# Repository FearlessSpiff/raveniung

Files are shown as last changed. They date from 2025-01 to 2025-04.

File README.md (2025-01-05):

# raveniung

Keyboard designed with ergogen, heavenly inspired by the reviung34

## Setup

* Install ergogen: `npm install -g ergogen`
* Get footprints from ceoloide: `git clone https://github.com/ceoloide/ergogen-footprints ergogen/footprints/ceoloide`

## Build

```bash
cd ergogen
ergogen .
```

## Notes

### Laser cutting (CR-Falcon Laser 10W)

#### Flux Oak Wood 3mm

* Outline and switch holes: Cut 2 times with 5mm/s 90% power
* M2 holes: Cut 2 times with 5mm/s 100% power

### Measurements

#### With PCB as top-plate and 3mm acryl top middle plate

* Standoffs must be 6mm high, 3mm diameter
* Screw from bottom M2x6mm (6.8mm total)
* Screw from top M2x4mm (4.8mm total)

#### With acryl as top-plate and 2mm? acryl top middle plate

* Standoffs must be 6mm
* Screw from bottom and bottom M2x6mm (6.8mm total)

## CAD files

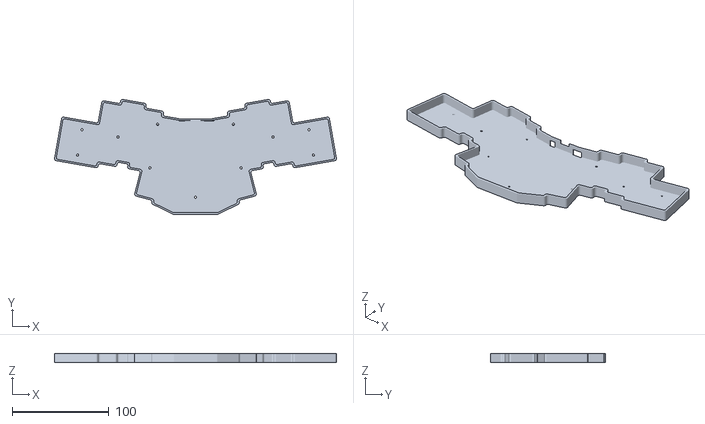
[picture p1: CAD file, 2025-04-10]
v0.1/Case/Case.stl
291.4 x 119.0 x 9.50

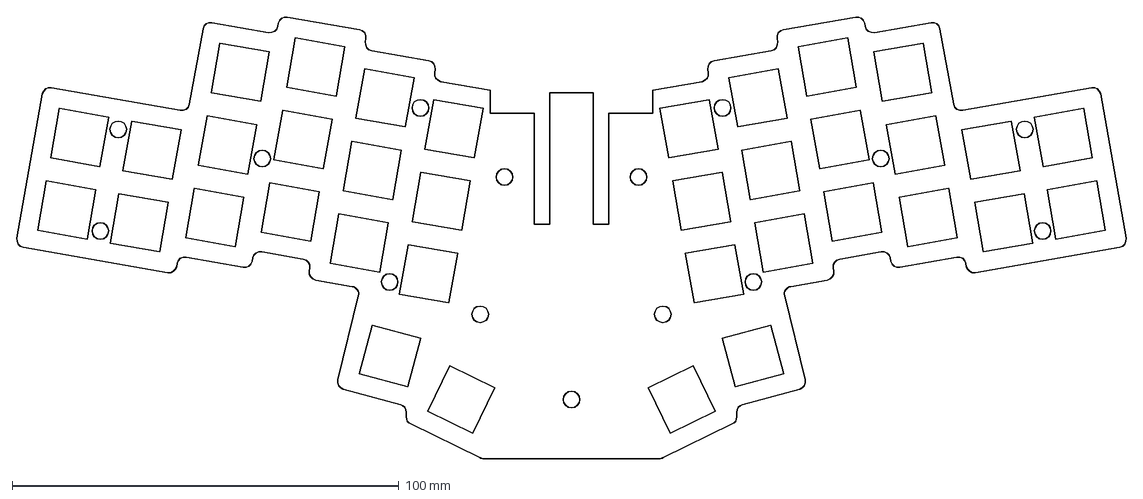
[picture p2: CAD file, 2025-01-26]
v0.1/Outlines/bottom-foam-plate.dxf
287.3 x 114.4 mm

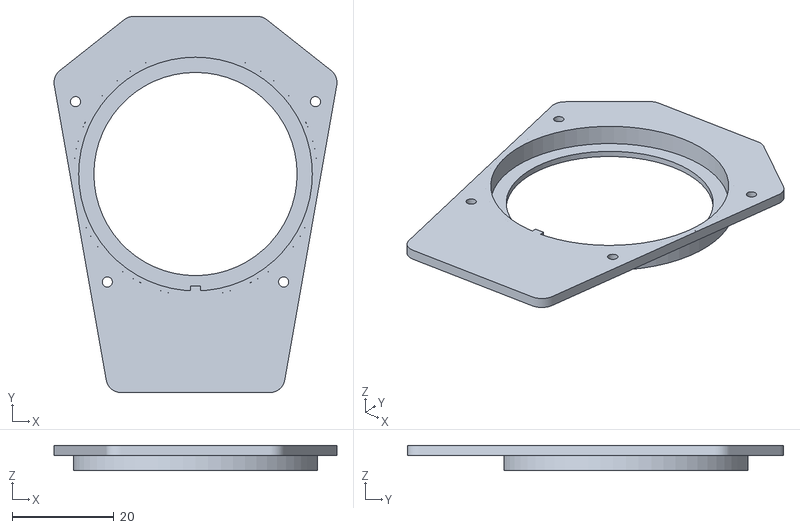
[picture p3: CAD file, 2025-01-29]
v0.1/STLs/Cirque Mount.stl
55.7 x 74.1 x 5.00

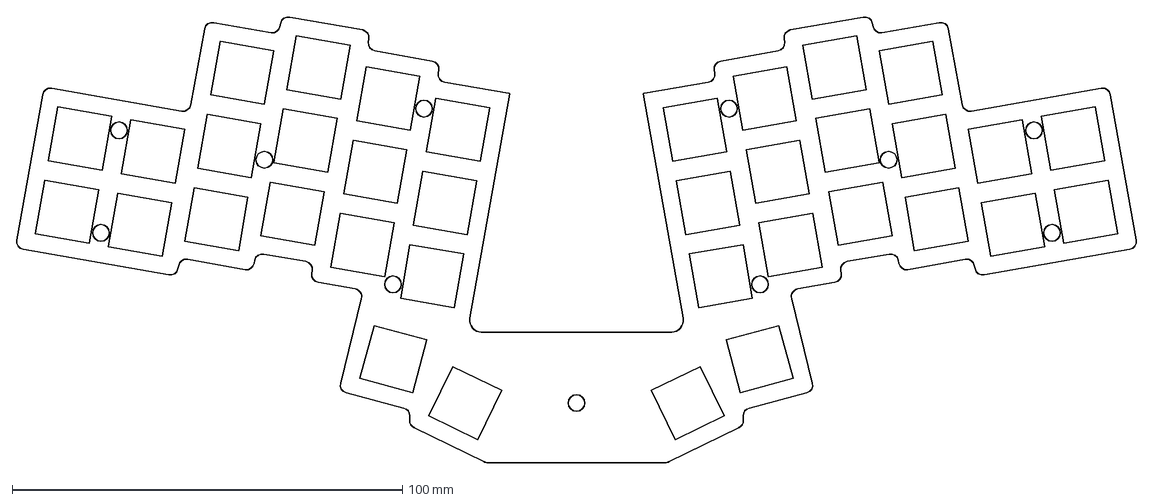
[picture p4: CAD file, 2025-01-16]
v0.1/Outlines/top-foam-plate.dxf
287.3 x 114.4 mm

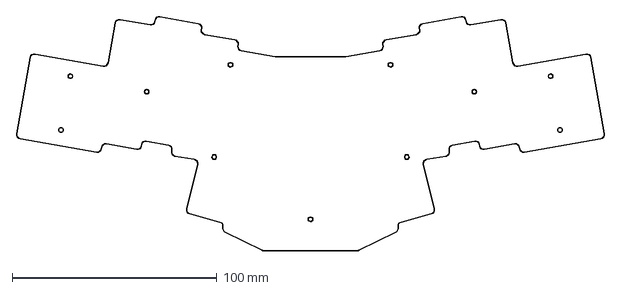
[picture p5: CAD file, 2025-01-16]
v0.1/Outlines/bottom-plate.dxf
287.3 x 114.4 mm

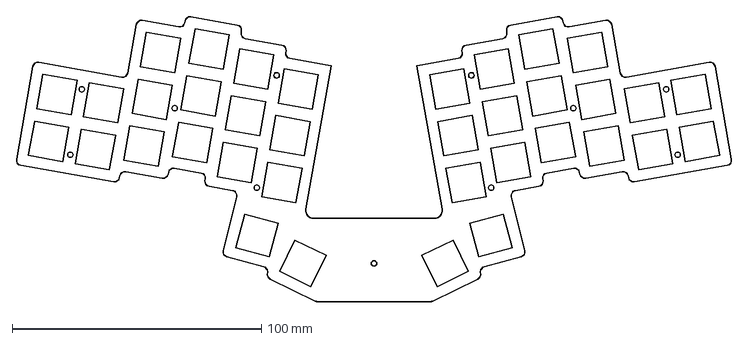
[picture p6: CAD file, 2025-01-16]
v0.1/Outlines/top-plate.dxf
287.3 x 114.4 mm

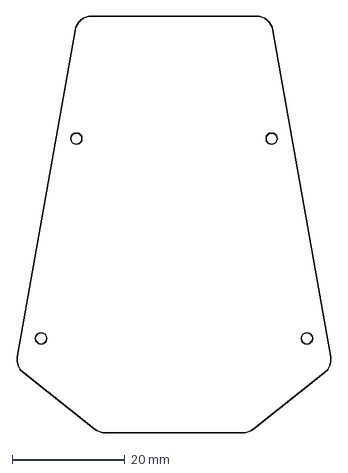
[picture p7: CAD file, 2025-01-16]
v0.1/Outlines/cover-simple.dxf
56.0 x 74.1 mm

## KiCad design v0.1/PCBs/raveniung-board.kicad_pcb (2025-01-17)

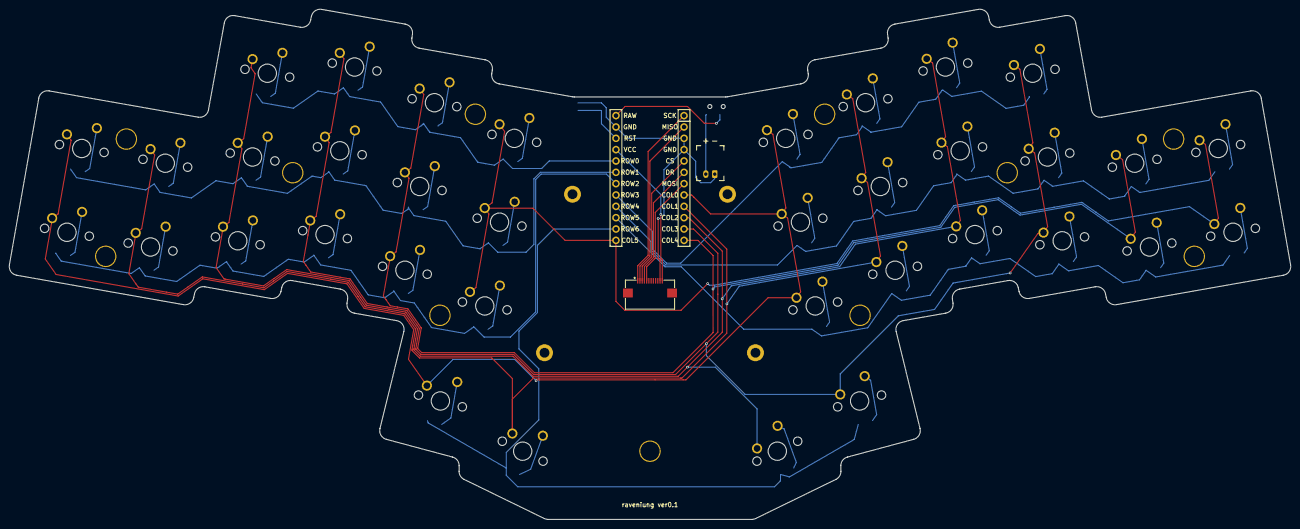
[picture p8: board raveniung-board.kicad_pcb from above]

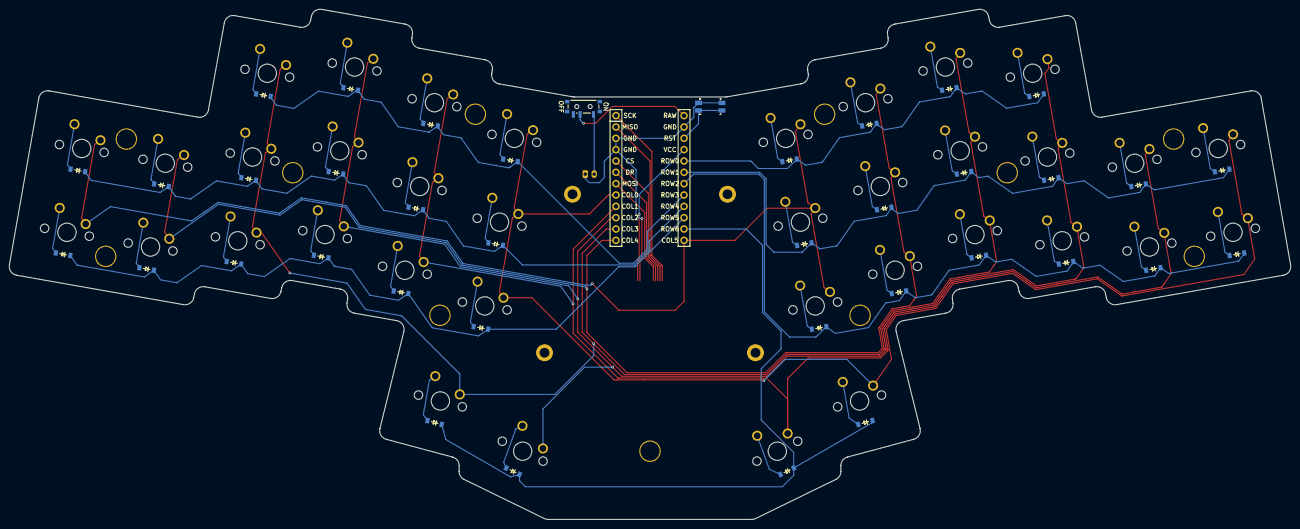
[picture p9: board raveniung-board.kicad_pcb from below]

Board: 2 copper layers, 287.0 x 114.2 mm, 92 parts (74 on the bottom side), 59 nets.

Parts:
D1, D2, D3, D4, D5, D6, D7, D8, D9, D10, D11, D12, D13, D14, D15, D16, D17, D18, D19, D20, D21, D22, D23, D24, D25, D26, D27, D28, D29, D30, D31, D32, D33, D34, D35, D36: diode_tht_sod123
FFC1: FPC-SMD_FPC05012-09200
H1, H2, H3, H4: mounting_hole_plated
JST1: battery_connector_jst_ph_2
MCU1: mcu_nice_nano
MH1, MH2, MH3, MH4, MH5, MH6, MH7, MH8, MH9, MH10, MH11: mounting_hole_npth
PWR1: power_switch_smd_side
RST1: reset_switch_smd_side
S1, S2, S3, S4, S5, S6, S7, S8, S9, S10, S11, S12, S13, S14, S15, S16, S17, S18, S19, S20, S21, S22, S23, S24, S25, S26, S27, S28, S29, S30, S31, S32, S33, S34, S35, S36: switch_mx

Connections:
BAT_P: JST1.2, PWR1.1
COL0: MCU1.8, S1.2, S2.2, S30.2, S31.2, S32.2, S34.2
COL1: MCU1.9, S3.2, S4.2, S27.2, S28.2, S29.2, S33.2
COL2: MCU1.10, S5.2, S6.2, S7.2, S24.2, S25.2, S26.2, S35.2
COL3: MCU1.11, S8.2, S9.2, S10.2, S21.2, S22.2, S23.2, S36.2
COL4: MCU1.12, S11.2, S12.2, S13.2, S19.2, S20.2
COL5: MCU1.13, S14.2, S15.2, S16.2, S17.2, S18.2
CS: FFC1.3, MCU1.5
DR: FFC1.4, MCU1.6
GND: FFC1.11, JST1.1, MCU1.3, MCU1.4, MCU1.23, RST1.1, RST1.3
MISO: FFC1.2, MCU1.2
MOSI: FFC1.5, MCU1.7
RAW: MCU1.24, PWR1.2
ROW0: D7.1, D10.1, D13.1, D16.1, MCU1.20
ROW1: D2.1, D4.1, D6.1, D9.1, D12.1, D15.1, MCU1.19
ROW2: D1.1, D3.1, D5.1, D8.1, D11.1, D14.1, MCU1.18
ROW3: D23.1, D26.1, D29.1, D32.1, MCU1.17
ROW4: D18.1, D20.1, D22.1, D25.1, D28.1, D31.1, MCU1.16
ROW5: D17.1, D19.1, D21.1, D24.1, D27.1, D30.1, MCU1.15
ROW6: D33.1, D34.1, D35.1, D36.1, MCU1.14
RST: MCU1.22, RST1.2, RST1.4
SCK: FFC1.1, MCU1.1
VCC: FFC1.12, MCU1.21
index_bottom: D11.2, S11.1
index_home: D12.2, S12.1
index_top: D13.2, S13.1
inner_bottom: D14.2, S14.1
inner_home: D15.2, S15.1
inner_thumb: D33.2, S33.1
inner_top: D16.2, S16.1
middle_bottom: D8.2, S8.1
middle_home: D9.2, S9.1
middle_top: D10.2, S10.1
mirror_index_bottom: D27.2, S27.1
mirror_index_home: D28.2, S28.1
mirror_index_top: D29.2, S29.1
mirror_inner_bottom: D30.2, S30.1
mirror_inner_home: D31.2, S31.1
mirror_inner_thumb: D35.2, S35.1
mirror_inner_top: D32.2, S32.1
mirror_middle_bottom: D24.2, S24.1
mirror_middle_home: D25.2, S25.1
mirror_middle_top: D26.2, S26.1
mirror_outer_bottom: D17.2, S17.1
mirror_outer_home: D18.2, S18.1
mirror_pinky_bottom: D19.2, S19.1
mirror_pinky_home: D20.2, S20.1
mirror_reachy_thumb: D36.2, S36.1
mirror_ring_bottom: D21.2, S21.1
mirror_ring_home: D22.2, S22.1
mirror_ring_top: D23.2, S23.1
outer_bottom: D1.2, S1.1
outer_home: D2.2, S2.1
pinky_bottom: D3.2, S3.1
pinky_home: D4.2, S4.1
reachy_thumb: D34.2, S34.1
ring_bottom: D5.2, S5.1
ring_home: D6.2, S6.1
ring_top: D7.2, S7.1

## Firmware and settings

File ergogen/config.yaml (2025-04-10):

units:
  angle: -10
  P: 0.6U
  caseOuter: 1.9
  caseInner: 0.3
  caseHoleRadius: 1.2
points:
  zones:
    matrix:
      # Fix placement on KiCAD sheet.
      anchor:
        shift: [100, -100]
      rotate: angle
      mirror: &mirror
        ref: matrix_inner_home
        shift: [0, -U]
        distance: 74
      columns:
        outer:
          key:
            column_net: COL0
            mirror.column_net: COL5
          rows:
            top:
              skip: true
        pinky:
          key:
            column_net: COL1
            mirror.column_net: COL4
          rows:
            top:
              skip: true
        ring:
          key:
            stagger: 0.25U
            column_net: COL2
            mirror.column_net: COL3
        middle:
          key:
            stagger: 0.25U
            column_net: COL3
            mirror.column_net: COL2
        index:
          key:
            stagger: -0.25U
            column_net: COL4
            mirror.column_net: COL1
        inner:
          key:
            stagger: -0.25U
            column_net: COL5
            mirror.column_net: COL0
      rows:
        bottom:
          padding: U
          row_net: ROW2
          mirror.row_net: ROW5
        home:
          padding: U
          row_net: ROW1
          mirror.row_net: ROW4
        top:
          padding: U
          row_net: ROW0
          mirror.row_net: ROW3
    thumbs:
      anchor:
        ref: matrix_inner_bottom
        shift: [0.75U, -1.5U]
        rotate: -8
      mirror: &mirror
        ref: matrix_inner_home
        shift: [0, -U]
        distance: 74
      columns:
        inner:
          key:
            rotate: -8
            shift: [0, -2]
            column_net: COL1
            mirror.column_net: COL2
        reachy:
          key:
            rotate: 3
            shift: [-40, 3]
            column_net: COL0
            mirror.column_net: COL3
      rows:
        thumb:
          row_net: ROW6
          mirror.row_net: ROW6
    standoff-top:
      mirror: *mirror
      anchor:
        ref: matrix_inner_home
        shift: [15, 9]
      key:
        name: standoff-top
        width: 1
        height: 1
    standoff-bottom:
      mirror: *mirror
      anchor:
        ref: matrix_inner_bottom
        shift: [15, -8]
      key:
        name: standoff-bottom
        width: 1
        height: 1
    mount-hole-middle:
      anchor:
        ref.aggregate.parts: [thumbs_inner_thumb, mirror_thumbs_inner_thumb]
        shift: [0, 0]
      key:
        name: mount-hole-middle
        width: 1
        height: 1
    mount-hole-inner-top:
      mirror: *mirror
      anchor:
        ref: matrix_inner_top
        shift: [-0.5U, 0.2U]
      key:
        name: mount-hole-inner-top
        width: 1
        height: 1
    mount-hole-inner-bottom:
      mirror: *mirror
      anchor:
        ref: matrix_inner_bottom
        shift: [-0.5U, -0.2U]
      key:
        name: mount-hole-inner-bottom
        width: 1
        height: 1
    mount-hole-middle-home:
      mirror: *mirror
      anchor:
        ref: matrix_middle_home
        shift: [-0.5U, -0.35U]
      key:
        name: mount-hole-middle-home
        width: 1
        height: 1
    mount-hole-pinky-home:
      mirror: *mirror
      anchor:
        ref: matrix_pinky_home
        shift: [-0.5U, 0.2U]
      key:
        name: mount-hole-pinky-home
        width: 1
        height: 1
    mount-hole-pinky-bottom:
      mirror: *mirror
      anchor:
        ref: matrix_pinky_bottom
        shift: [-0.5U, -0.2U]
      key:
        name: mount-hole-pinky-bottom
        width: 1
        height: 1
    mcu-solder-points:
      mirror: *mirror
      anchor:
        ref.aggregate.parts: [matrix_inner_home, mirror_matrix_inner_home]
        shift: [-7.6, 12]
      key:
        name: mcu-solder-points
        width: 1
        height: 1
    power-switch-footprint:
      anchor:
        ref.aggregate.parts: [matrix_inner_top, mirror_matrix_inner_top]
        shift: [14, 8]
      key:
        name: power-switch-footprint
        width: 1
        height: 1
    reset-switch-footprint:
      anchor:
        ref.aggregate.parts: [matrix_inner_top, mirror_matrix_inner_top]
        shift: [-14, 8]
      key:
        name: reset-switch-footprint
        width: 1
        height: 1
outlines:
  keycaps:
    - what: rectangle
      where:
        - /matrix_.*/
        - /thumbs_.*/
      size: [U-0.5, U-0.5]
  keys:
    - what: rectangle
      where:
        - /matrix_.*/
        - /thumbs_.*/
      size: [14, 14]
  keys-diodes-solder:
    - what: rectangle
      where:
        - /matrix_.*/
        - /thumbs_.*/
      size: [13, 13]
  board:
    - what: polygon
      operation: stack
      fillet: 2
      points:
        - ref: matrix_outer_home
          shift: [-P, P]
        - ref: matrix_pinky_home
          shift: [-P, P]
        - ref: matrix_pinky_home
          shift: [0.65P, P]
        - ref: matrix_ring_top
          shift: [-P, P]
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

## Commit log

2024-12-04 add outlines and some things on the pcb
2024-12-05 add ceoloide footprints
2024-12-05 add reviung41 style keyboard matrix and wiring
2024-12-08 add correct top plate with cherry cutouts
    [config.yaml]
2024-12-11 before standoffs
2024-12-11 add standoffs, comment out unknown parts for celoide ergogen
2024-12-11 switch to 10 degree angle, more like reviung34
2024-12-11 add mounting holes and better thumb position
2024-12-12 better thumb position, fixes and simlplifications
    [config.yaml]
2024-12-12 add battery, mounting holes and standoffs to pcb
2024-12-12 add top plate pcb
2024-12-12 add version label to pcbs
2024-12-12 change reset switch to smd one and place reset and power switch on top of pcb
    [config.yaml]
2024-12-13 add bottom plate
2024-12-17 move pinky bottom mount hole a bit less to the side
2024-12-19 use ceoloide diode
2024-12-19 completely rectangular board form
2024-12-19 move mount holes for new board shape
2024-12-19 add measuremnts of standoffs and screws to readme.md
2024-12-19 add a simpler cover plate to show off the wood top plate if wanted
2024-12-19 document laser settings for wood plate
2024-12-19 add cirque colors according to test wiring on breadboard
2024-12-19 change pcb mounting hole radius for standoff size
2024-12-20 set keycap size to mx switch width to better see what happens with the standoff holes
2024-12-30 add breadboard wire cables and mcu pins
2024-12-31 add own 0.5mm FFC connector
2024-12-31 change switch wiring direction
2024-12-31 move battery connector inside
2024-12-31 fix header of own footprint
2025-01-04 add outline for mechanical pcb preview
2025-01-04 fix top-plate mount hole radius and add top foam plate, which is the same as the top plate atm
    [config.yaml]
2025-01-04 start with bottom foam plate
2025-01-05 remove pcb mechanical preview as it is easier to be done in KiCad
2025-01-05 move battery connector to other side as it's easier for routing
2025-01-05 move battery connector for easier routing
2025-01-05 finish bottom foam plate
2025-01-05 fix foam plate hole sizes
    [config.yaml]
2025-01-05 fix bottom plate hole size
    [config.yaml]
2025-01-07 move power switch under mcu as there is not enough place with the top plate
2025-01-08 move reset and power switch to bottom
    [config.yaml]
2025-01-10 add PCBs
    [raveniung-board.kicad_pcb, raveniung-top-plate.kicad_pcb]
2025-01-10 fix thumb cluster definition
    [config.yaml]
2025-01-10 fix typo and bug in mirro column net for thumb cluster
    [config.yaml]
2025-01-14 make ffc side pads bigger for easier manual soldering
2025-01-14 add some unwanted kicad stuff to gitignore
2025-01-16 add power and reset switch to bottom foam plate
2025-01-16 add other kicad stuff to gitignore
2025-01-16 add v0.1 outlines and stls
    [Cirque Mount Low.stl, bottom-foam-plate.dxf, bottom-plate.dxf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]
2025-01-16 add routed v0.1 PCBs
    [raveniung-board.kicad_pcb, raveniung-top-plate.kicad_pcb]
2025-01-17 add v0.1 gerbers
    [raveniung-board.kicad_pcb]
2025-01-26 fix bottom foam plate for 0.1
    [bottom-foam-plate.dxf]
2025-01-29 fix cirque direction for 0.1
    [Cirque Mount Low.stl, Cirque Mount.stl]
2025-04-10 Add a case
    This gives error as stl has problems, that can't seem to be fixed.
    Nevertheless prints fine in Bambustudio
    [Case.stl]
